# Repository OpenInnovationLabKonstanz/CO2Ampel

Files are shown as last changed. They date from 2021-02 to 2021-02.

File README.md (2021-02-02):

# CO2Ampel
A device for visual representation of  CO2 concentraition in the air. Helps monitoring air quality in order to reduce the risk of COVID19 infections in closed rooms.

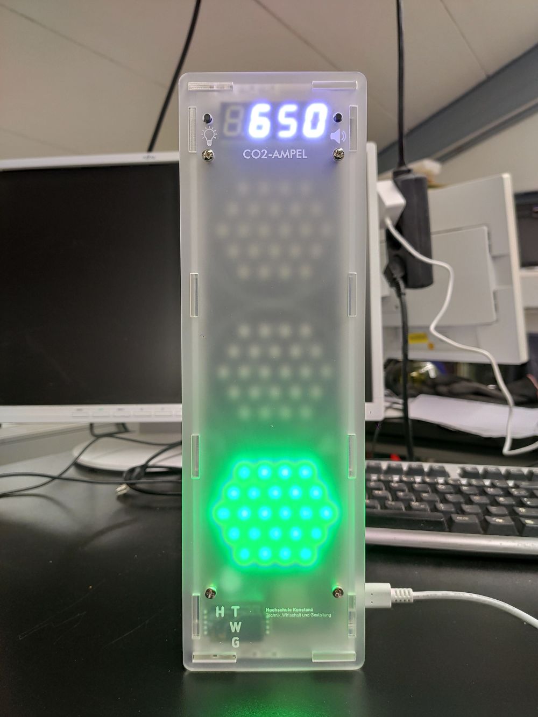
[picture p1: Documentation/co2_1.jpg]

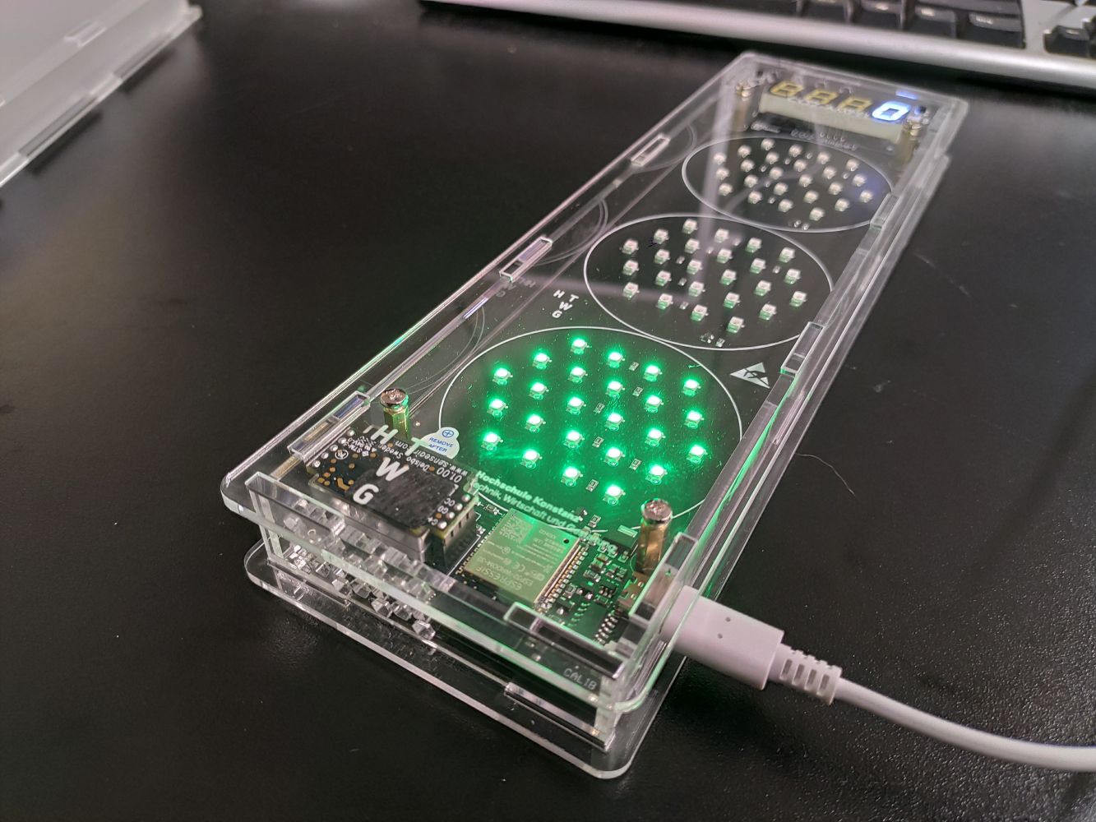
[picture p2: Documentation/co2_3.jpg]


## Project Overview

ToDo: ...

## Hardware

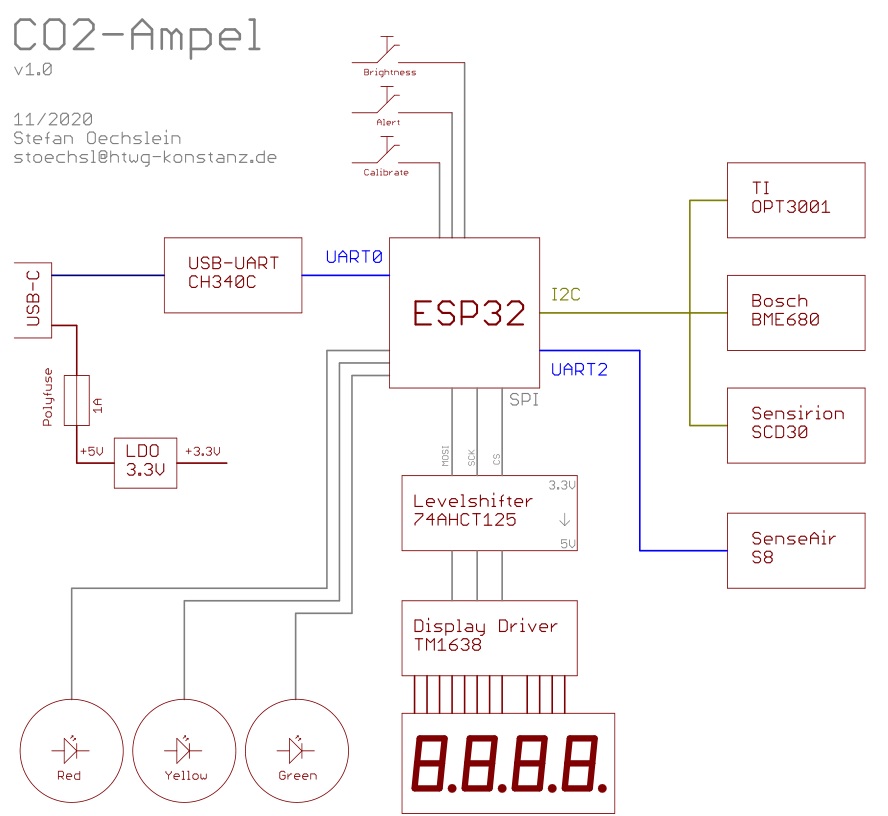
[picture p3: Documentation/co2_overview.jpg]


The device consists of a CO2 sensor, connected to a ESP32-WROOM-32 as main controller. Three large LED arrays (red, yellow, green) are used as a indicator for air quality. In addition, a numeric display shows the current CO2 concentration in ppm.

### CO2 Sensor
Due to the bad availability of CO2 sensors during the COVID19 pandemic, multiple sensor types are supported.
* SenseAir S8 (UART)
* MH-Z19B (pin-compatible to the S8)
* Sensirion SCD30 (I2C)

### Environment Sensor
As an additional method of air quality measurement, a Bosch BME680 multi environmental sensor is used. 
It provides temperature, rel. humidity, air pressure and VOC (volatile organic compounds) measurement.

### Ambient Light Sensor
In order to adapt the display and LED brightness, a OPT3001 ambient light 

### Display
A 4-digit 7-segment display, driven by a TitanMicro TM1638 is used to display the current CO2 concentration (in ppm).

## PCB
The PCB is routed as a 2-layer PCB. Parts are only placed on the top side in order to facilitate mass production.
Layout files are provided as Eagle 6.4 .brd and .sch files.

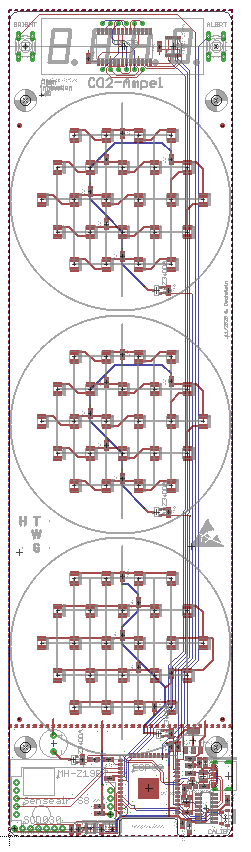
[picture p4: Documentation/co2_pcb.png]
PCB


## Software
The firmware for the ESP32 is written in Arduino, using the ESP32-Arduino support package.
It uses following external libraries:
* SparkFun SCD30 Library (ToDo: Link)
* ClosedCube OPT3001 Library (ToDo: Link)
* Adafruit Sensor Library (ToDo: Link)
* Adafruit BME680 Library (ToDo: Link)
* ...

## Mechanical
The housing is laser-cut from 3mm acrylic sheets. Use sheets with satin finish for better light dispersion (eg. TroGlass Satin).
DXF files for cutting and engraving are provided in *Mechanical*.

## Contact
Stefan Oechslein, Open Innovation Lab Konstanz, oil@htwg-konstanz.de

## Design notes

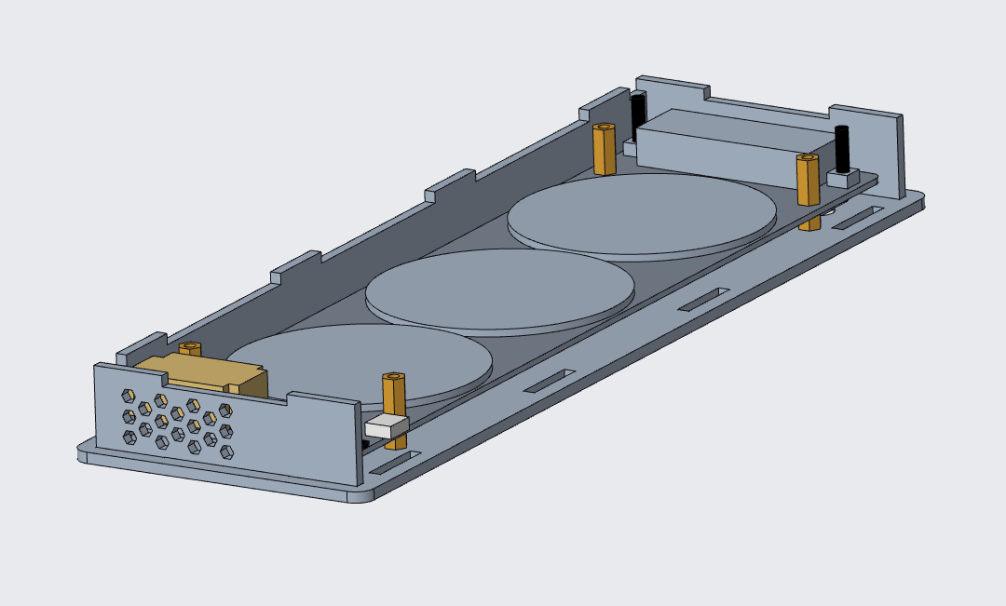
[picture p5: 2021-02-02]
Documentation/co2_cad1.png

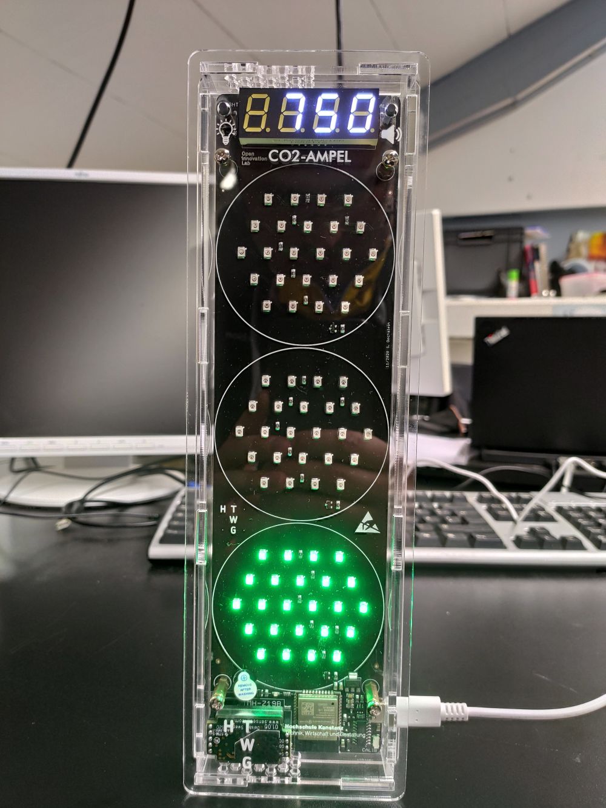
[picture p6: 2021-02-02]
Documentation/co2_2.jpg

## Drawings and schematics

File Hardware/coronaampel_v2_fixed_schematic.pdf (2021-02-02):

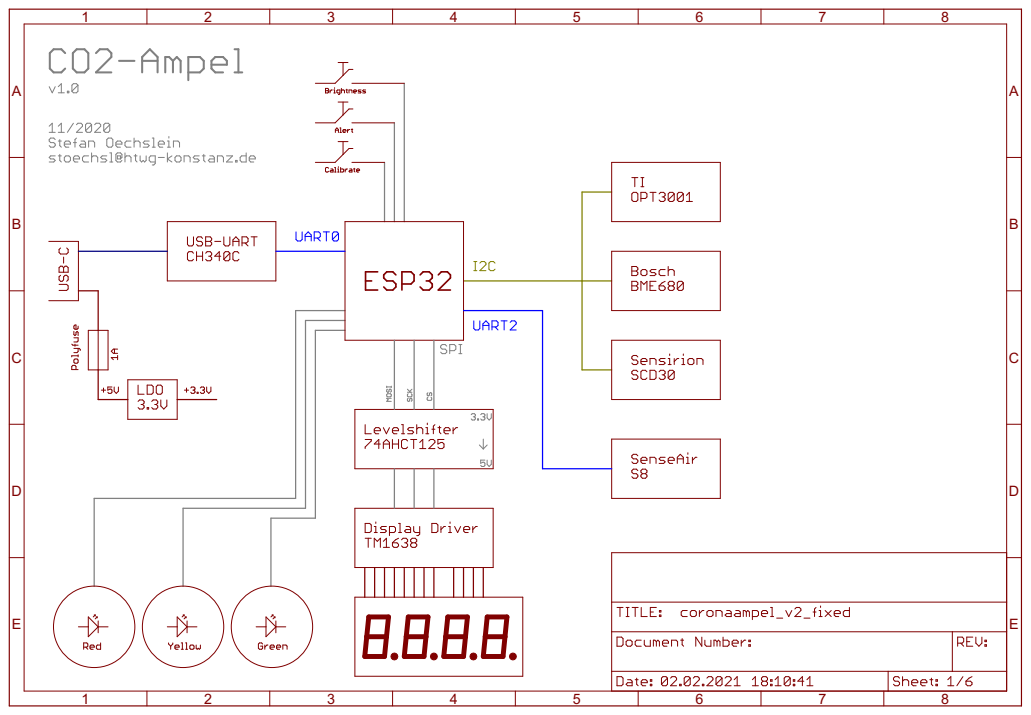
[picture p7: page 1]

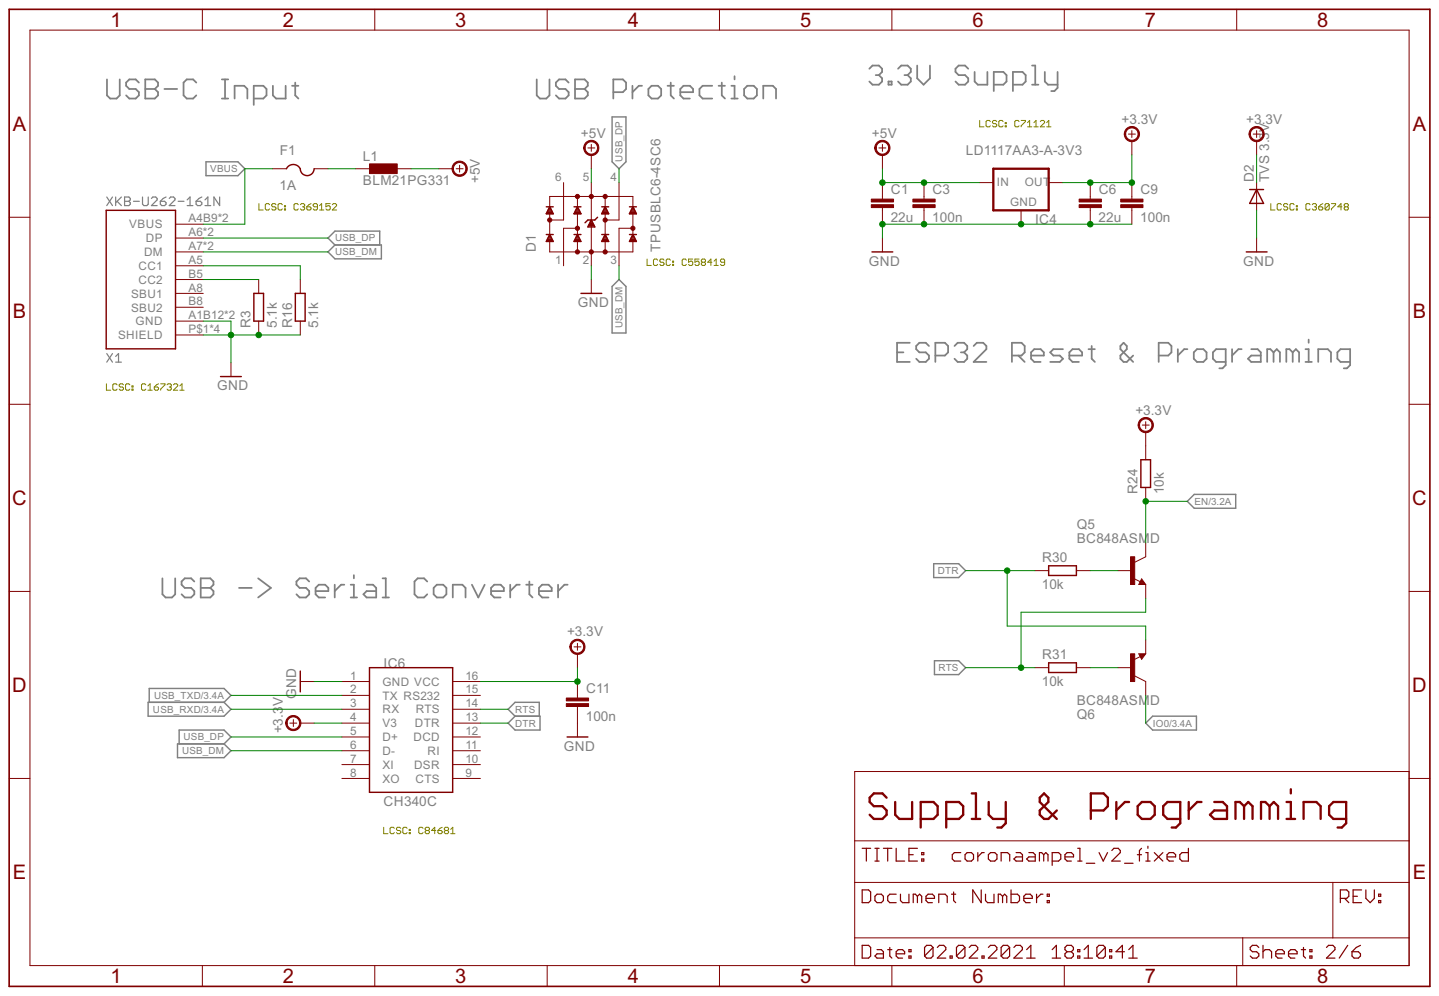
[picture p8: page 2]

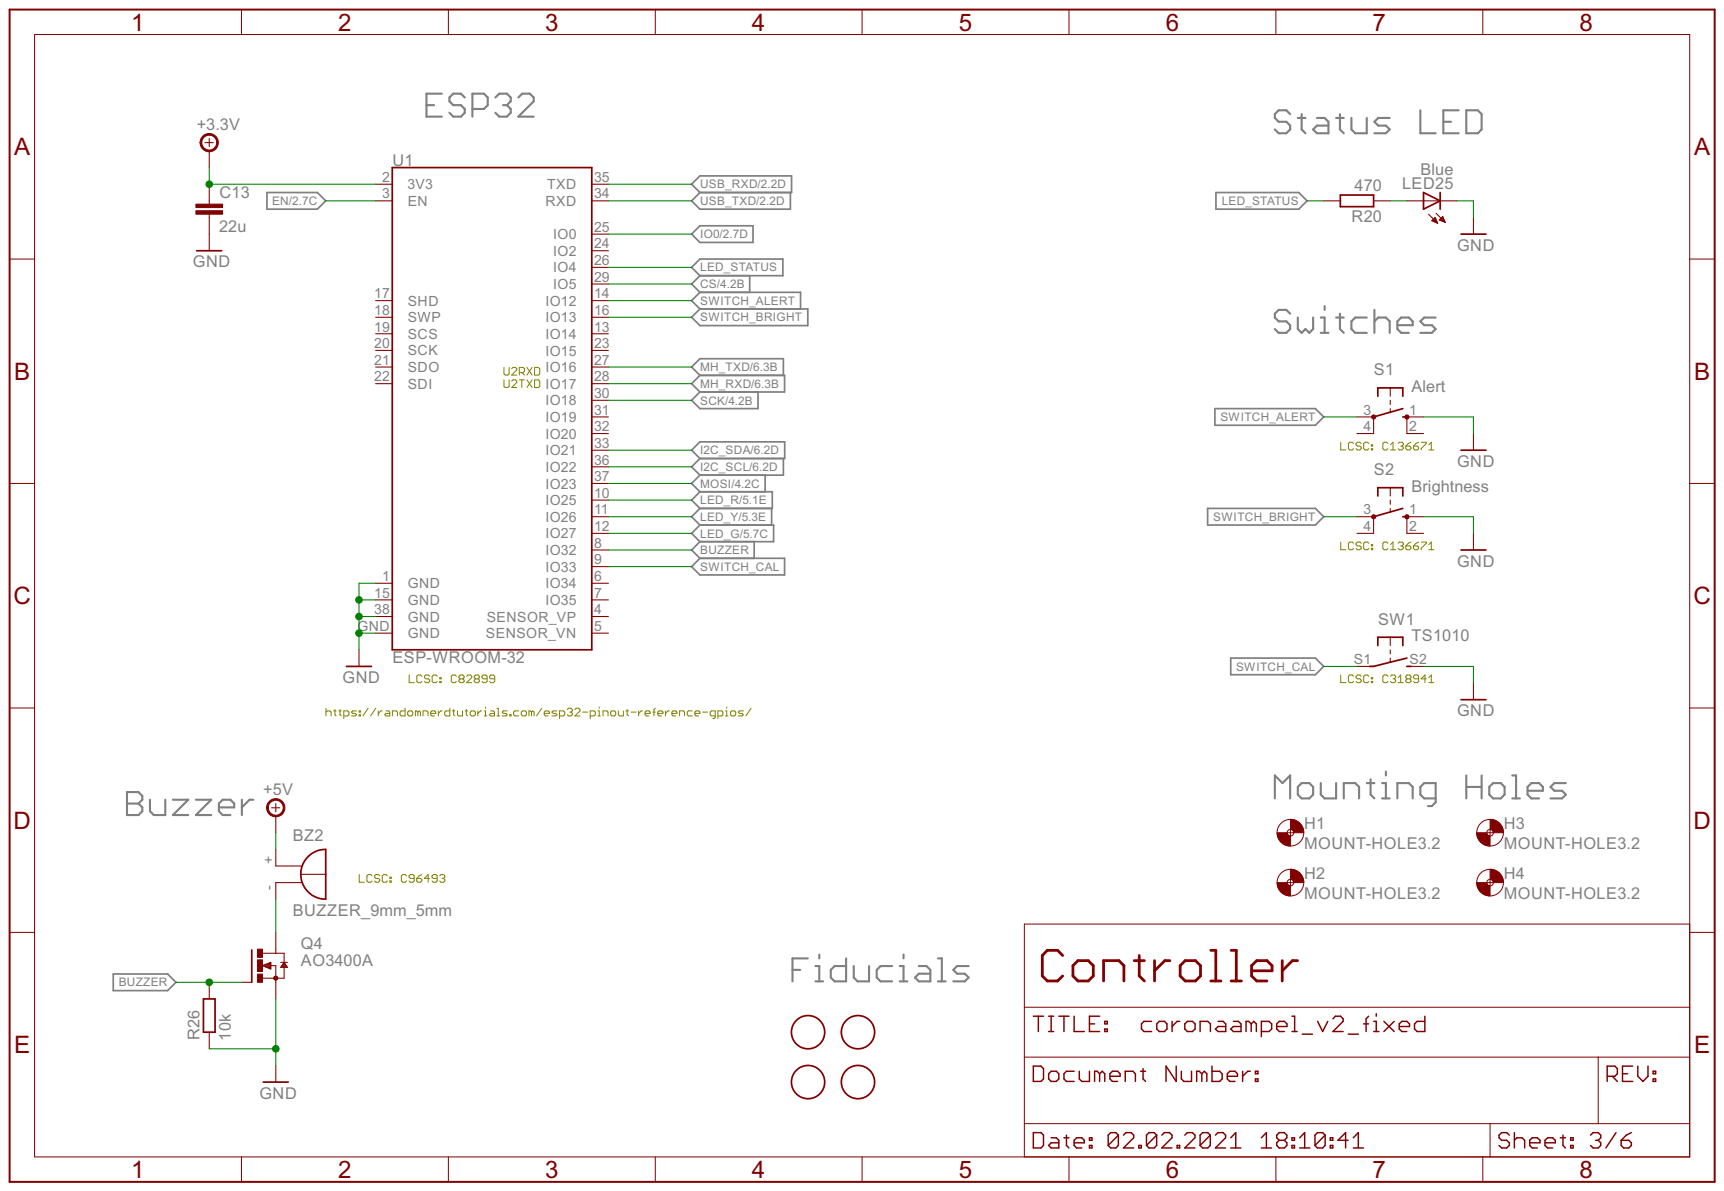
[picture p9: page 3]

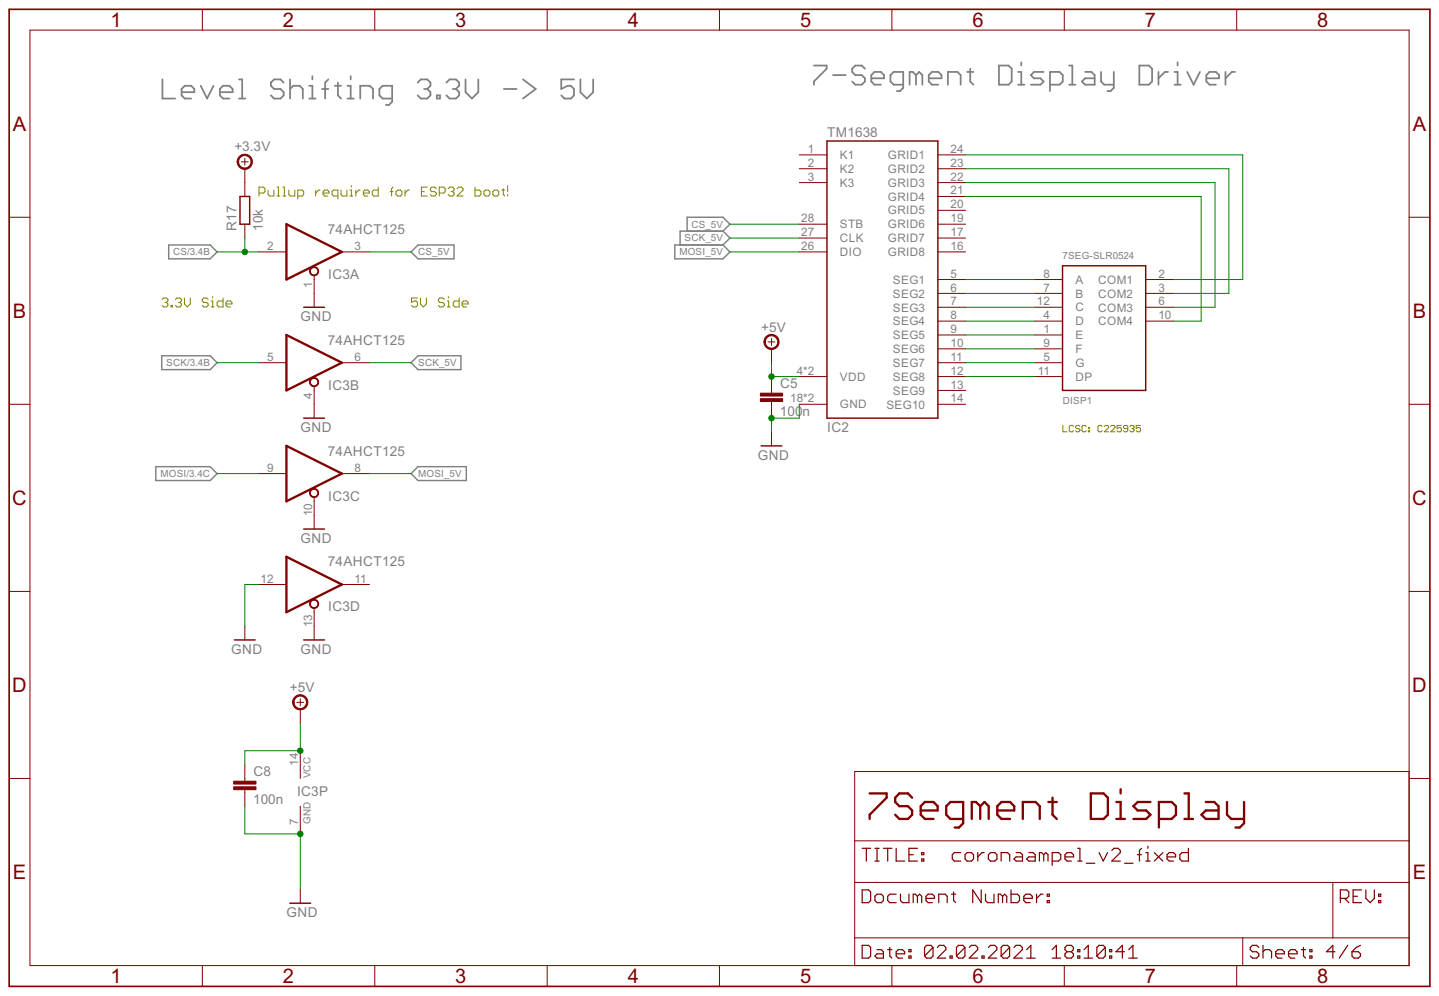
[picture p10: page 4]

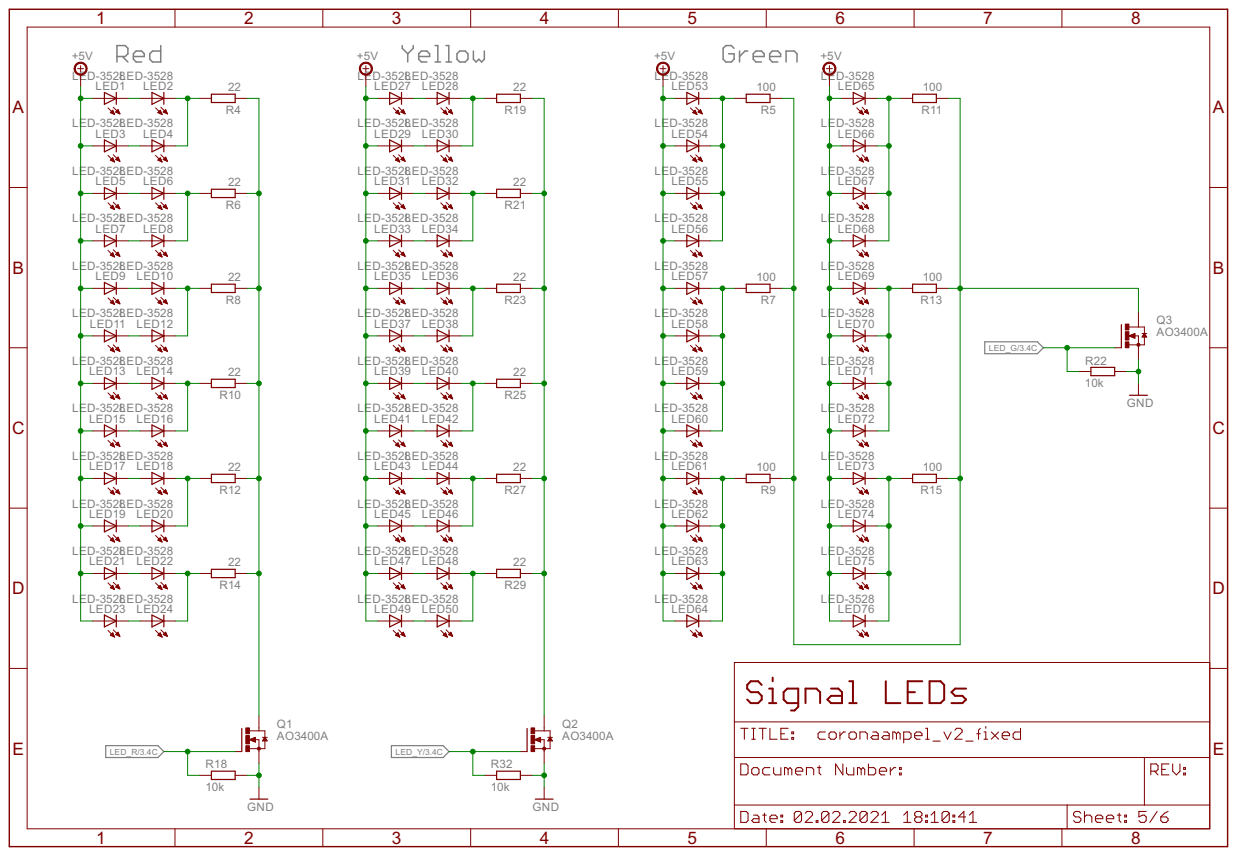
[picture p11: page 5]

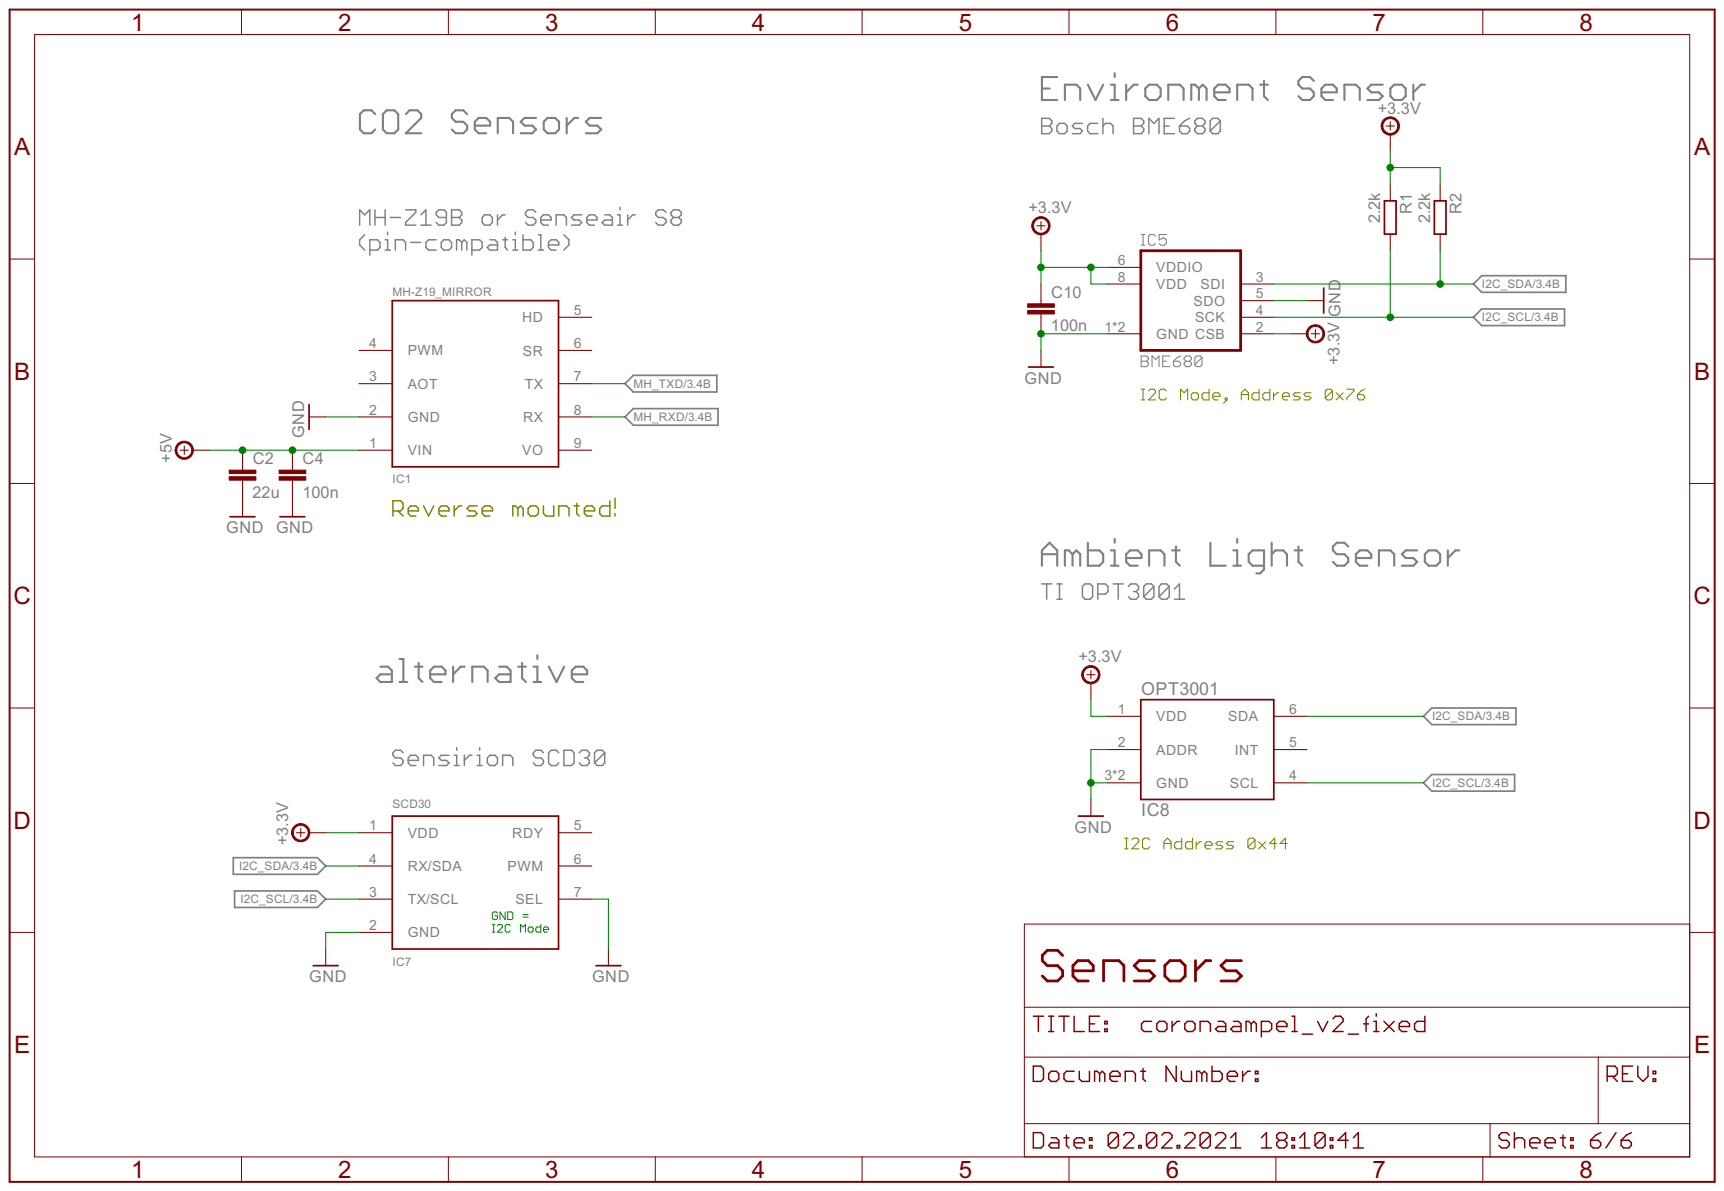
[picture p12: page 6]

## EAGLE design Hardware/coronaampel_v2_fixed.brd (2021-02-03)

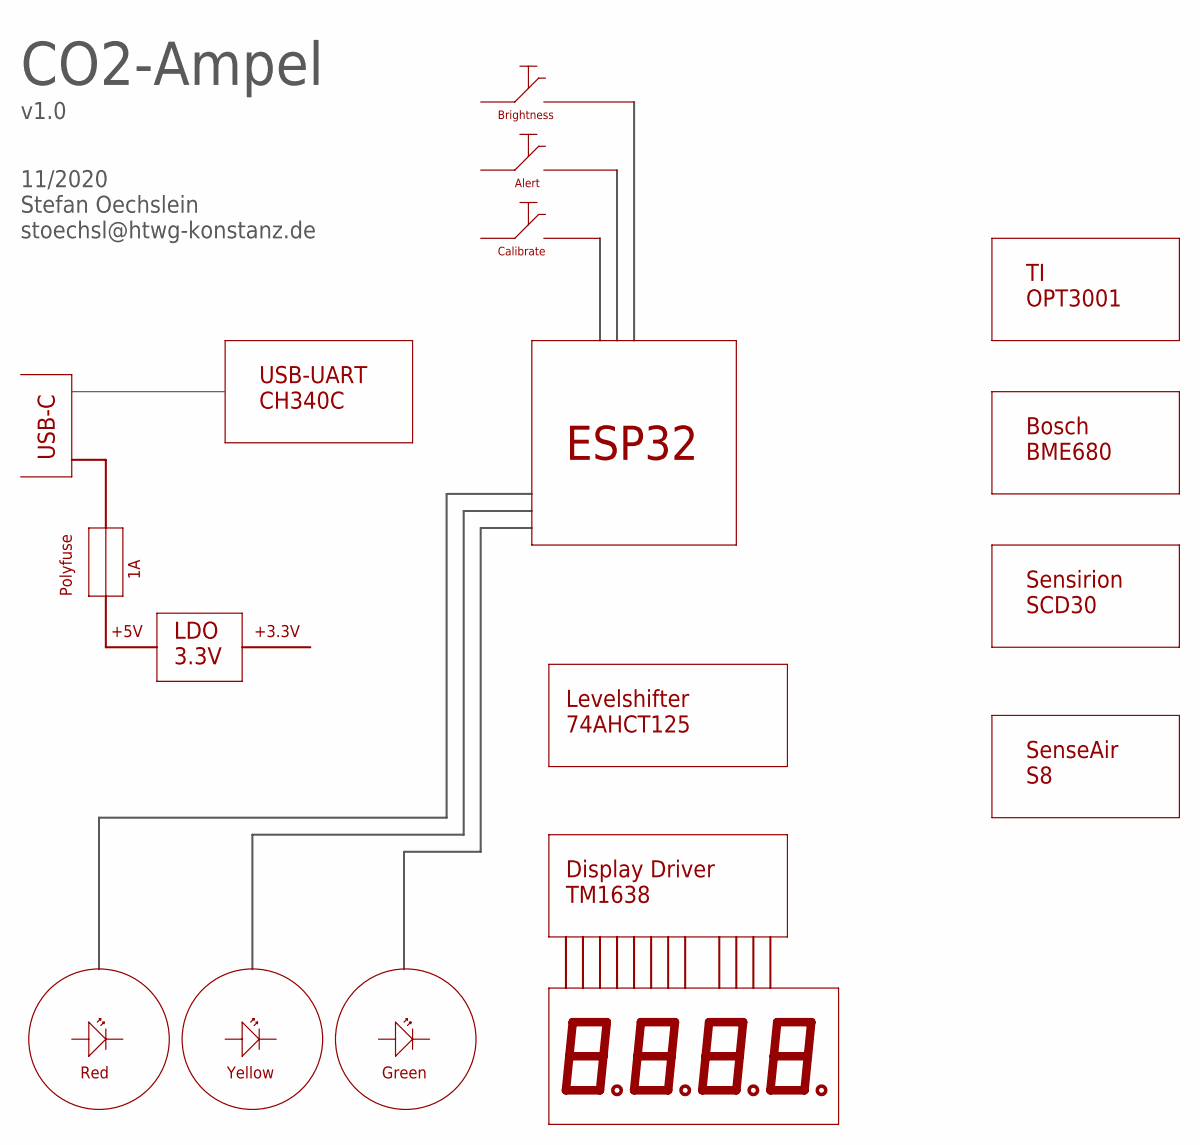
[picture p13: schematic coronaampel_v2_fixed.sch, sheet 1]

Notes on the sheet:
CO2-Ampel
ESP32
Sensirion SCD30
SenseAir S8
Bosch BME680
TI OPT3001
USB-UART CH340C
USB-C
LDO 3.3V
Display Driver TM1638
Levelshifter 74AHCT125
Polyfuse
+5V
+3.3V
Red
Yellow
Green
Alert
Calibrate
Brightness
v1.0
11/2020 Stefan Oechslein stoechsl@htwg-konstanz.de

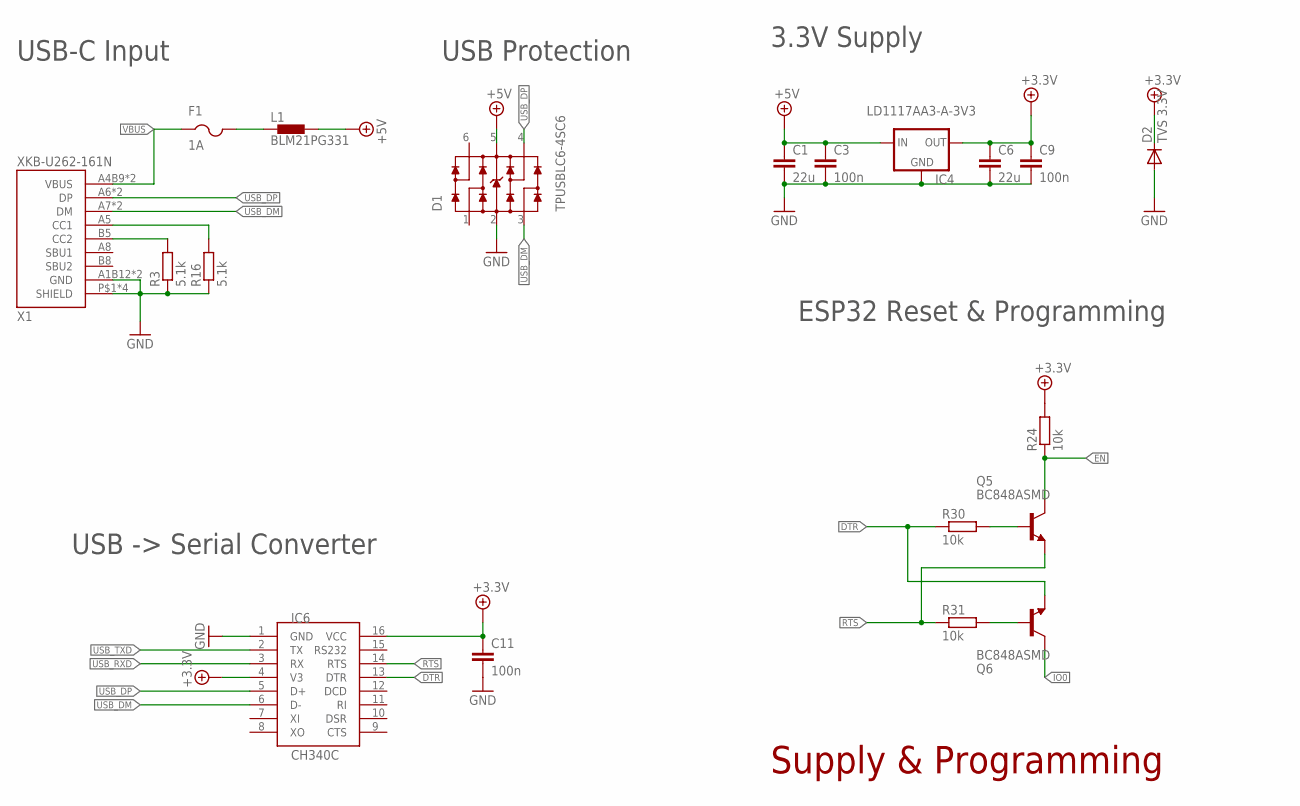
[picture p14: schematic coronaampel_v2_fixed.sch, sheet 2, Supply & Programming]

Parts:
C1, C6: 22u; C0805
C3, C9, C11: 100n; C0805
D1: TPUSBLC6-4SC6; WE-TVS_SOT23-6L
D2: TVS 3.3V; SOD123
F1: 1A; R0805
IC4: LD1117AA3-A-3V3; SOT223
IC6: CH340C; SOIC16
L1: BLM21PG331; 0805
Q5, Q6: BC848ASMD; SOT23
R3, R16: 5.1k; R0805
R24, R30, R31: 10k; R0805
X1: XKB-U262-161N; XKB_U262-161N

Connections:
+3,3V: C6.1, C9.1, C11.1, D2.C, IC4.2 (OUT), IC4.4 (OUT), IC6.4 (V3), IC6.16 (VCC), R24.2; also elsewhere on the board
+5V: C1.1, C3.1, D1.5 (VDD), IC4.3 (IN), L1.2; also elsewhere on the board
CC1: R16.2, X1.A5 (CC1)
CC2: R3.2, X1.B5 (CC2)
DTR: IC6.13 (DTR), Q6.2 (E), R30.1
EN: Q5.3 (C), R24.1; also elsewhere on the board
GND: C1.2, C3.2, C6.2, C9.2, C11.2, D1.2 (GND), D2.A, IC4.1 (GND), IC6.1 (GND), R3.1, R16.1, X1.A1B12 (GND), X1.B1A12 (GND), X1.P$1 (SHIELD), X1.P$2 (SHIELD), X1.P$3 (SHIELD), X1.P$4 (SHIELD); also elsewhere on the board
IO0: Q6.3 (C); also elsewhere on the board
unnamed: Q6.1 (B), R31.2
unnamed: Q5.1 (B), R30.2
RTS: IC6.14 (RTS), Q5.2 (E), R31.1
USB_DM: D1.3 (2), IC6.6 (D-), X1.A7 (DM), X1.B7 (DM)
USB_DP: D1.4 (3), IC6.5 (D+), X1.A6 (DP), X1.B6 (DP)
USB_RXD: IC6.3 (RX); also elsewhere on the board
USB_TXD: IC6.2 (TX); also elsewhere on the board
VBUS: F1.1, X1.A4B9 (VBUS), X1.B4A9 (VBUS)
VIN: F1.2, L1.1

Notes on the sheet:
USB -> Serial Converter
ESP32 Reset & Programming
USB-C Input
USB Protection
3.3V Supply
Supply & Programming

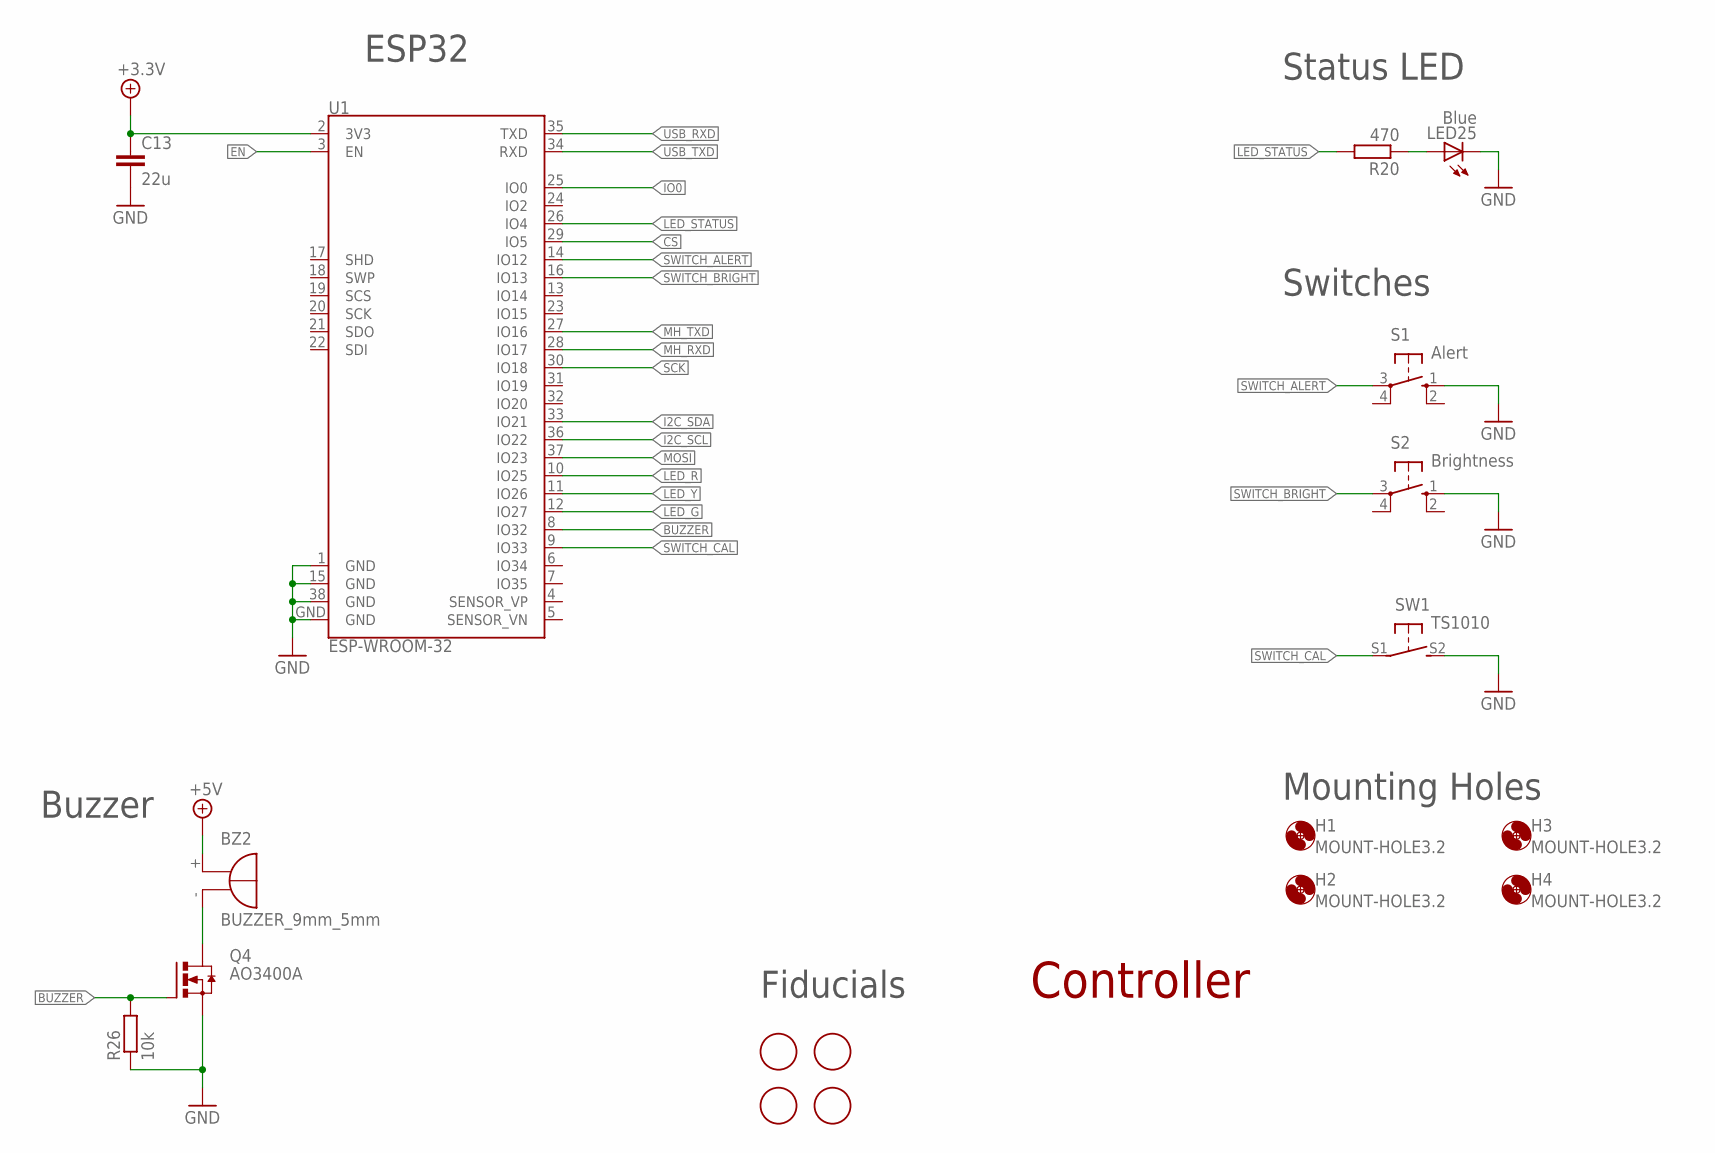
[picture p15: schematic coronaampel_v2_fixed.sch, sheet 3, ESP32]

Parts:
BZ2: BUZZER_9mm_5mm; BUZ_9_5
C13: 22u; C0805
H1, H2, H3, H4: MOUNT-HOLE3.2; 3,2
LED25: Blue; CHIPLED_0805
Q4: AO3400A; MICRO3
R20: 470; R0805
R26: 10k; R0805
S1: Alert; B3F-10XX
S2: Brightness; B3F-10XX
SW1: TS1010
U1: ESP-WROOM-32
U$4, U$6, U$7, U$8: FIDUCIAL; FIDUCIAL_1MM

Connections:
+3,3V: C13.1, U1.2 (3V3); also elsewhere on the board
+5V: BZ2.+; also elsewhere on the board
BUZ: BZ2.-, Q4.3 (D)
BUZZER: Q4.1 (G), R26.2, U1.8 (IO32)
CS: U1.29 (IO5); also elsewhere on the board
EN: U1.3 (EN); also elsewhere on the board
GND: C13.2, LED25.C, Q4.2 (S), R26.1, S1.1 (S), S2.1 (S), SW1.S2 (S), U1.1 (GND), U1.15 (GND), U1.38 (GND), U1.GND; also elsewhere on the board
I2C_SCL: U1.36 (IO22); also elsewhere on the board
I2C_SDA: U1.33 (IO21); also elsewhere on the board
IO0: U1.25 (IO0); also elsewhere on the board
LED_G: U1.12 (IO27); also elsewhere on the board
LED_R: U1.10 (IO25); also elsewhere on the board
LED_STATUS: R20.2, U1.26 (IO4)
LED_Y: U1.11 (IO26); also elsewhere on the board
MH_RXD: U1.28 (IO17); also elsewhere on the board
MH_TXD: U1.27 (IO16); also elsewhere on the board
MOSI: U1.37 (IO23); also elsewhere on the board
unnamed: LED25.A, R20.1
SCK: U1.30 (IO18); also elsewhere on the board
SWITCH_ALERT: S1.3, U1.14 (IO12)
SWITCH_BRIGHT: S2.3, U1.16 (IO13)
SWITCH_CAL: SW1.S1, U1.9 (IO33)
USB_RXD: U1.35 (TXD); also elsewhere on the board
USB_TXD: U1.34 (RXD); also elsewhere on the board

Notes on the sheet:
Buzzer
Status LED
Switches
ESP32
Controller
Fiducials
Mounting Holes

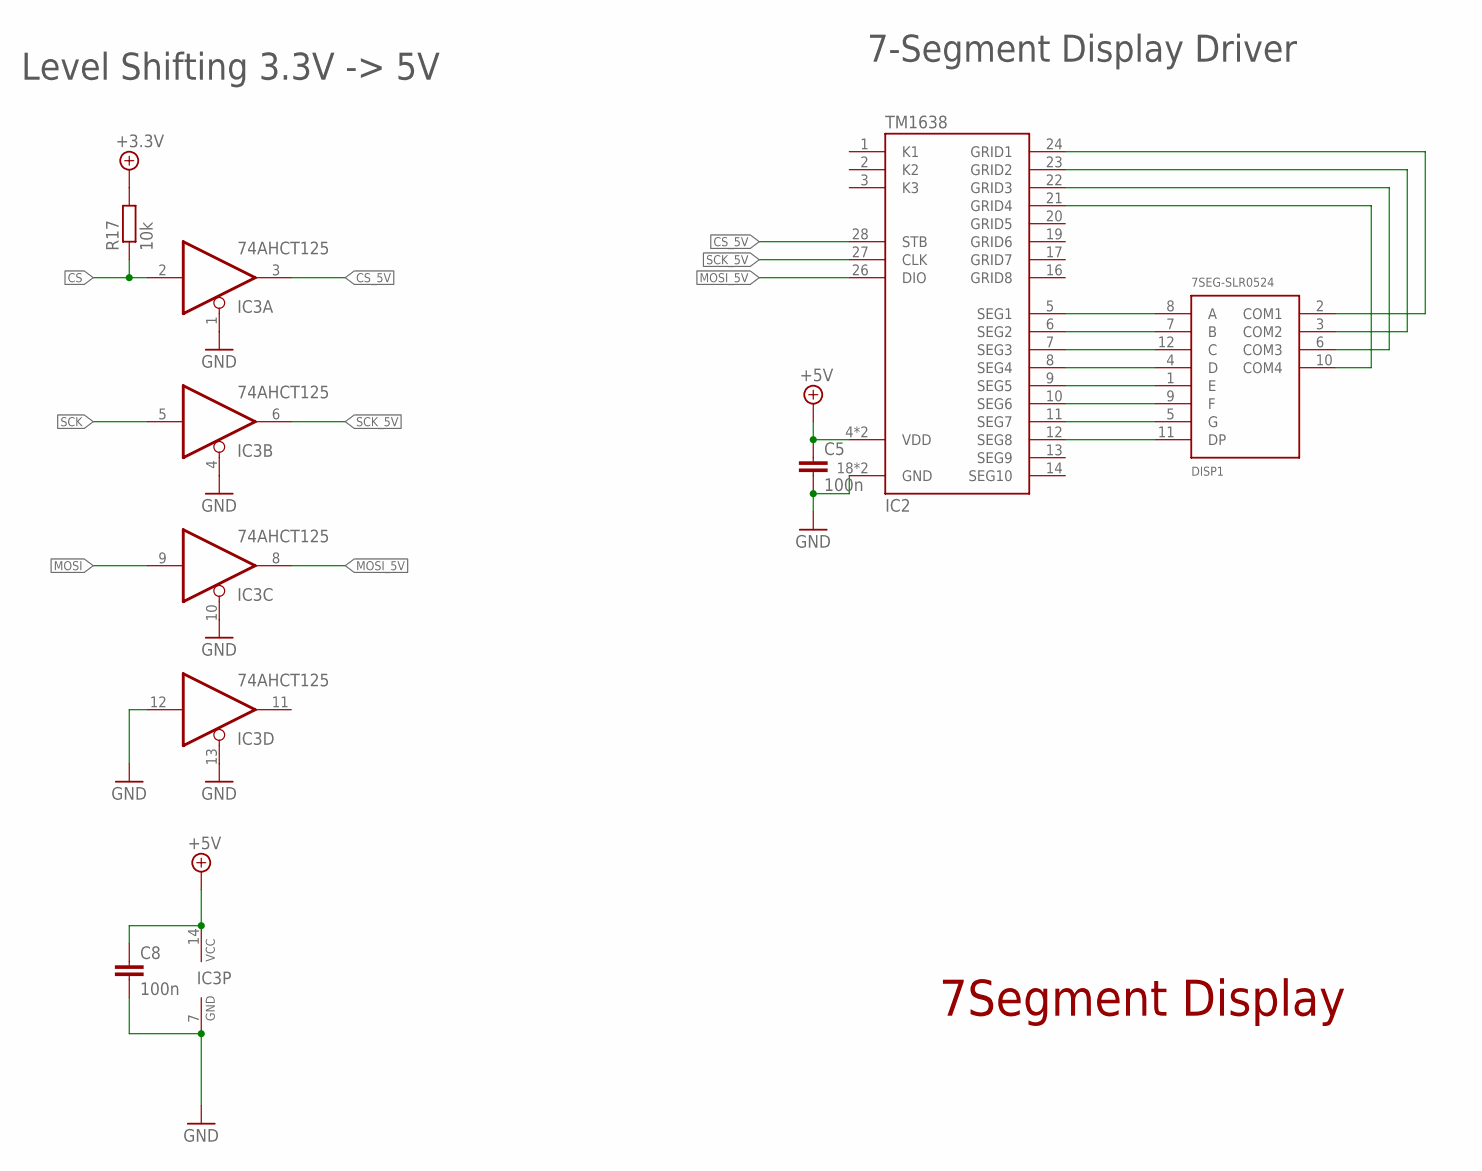
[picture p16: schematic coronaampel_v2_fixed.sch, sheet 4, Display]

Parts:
C5, C8: 100n; C0805
DISP1: 7SEG-SLR0524; SEG-SLR0524
IC2: TM1638; SO-28L
IC3: 74AHCT125; TSSOP14
R17: 10k; R0805

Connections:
+3,3V: R17.2; also elsewhere on the board
+5V: C5.1, C8.1, IC2.4 (VDD), IC2.15 (VDD), IC3.14 (VCC); also elsewhere on the board
CS: IC3.2 (I), R17.1; also elsewhere on the board
CS_5V: IC2.28 (STB), IC3.3 (O)
GND: C5.2, C8.2, IC2.18 (GND), IC2.25 (GND), IC3.1 (OE), IC3.4 (OE), IC3.7 (GND), IC3.10 (OE), IC3.12 (I), IC3.13 (OE); also elsewhere on the board
GRID1: DISP1.2 (COM1), IC2.24 (GRID1)
GRID2: DISP1.3 (COM2), IC2.23 (GRID2)
GRID3: DISP1.6 (COM3), IC2.22 (GRID3)
GRID4: DISP1.10 (COM4), IC2.21 (GRID4)
MOSI: IC3.9 (I); also elsewhere on the board
MOSI_5V: IC2.26 (DIO), IC3.8 (O)
SCK: IC3.5 (I); also elsewhere on the board
SCK_5V: IC2.27 (CLK), IC3.6 (O)
SEG1: DISP1.8 (A), IC2.5 (SEG1)
SEG2: DISP1.7 (B), IC2.6 (SEG2)
SEG3: DISP1.12 (C), IC2.7 (SEG3)
SEG4: DISP1.4 (D), IC2.8 (SEG4)
SEG5: DISP1.1 (E), IC2.9 (SEG5)
SEG6: DISP1.9 (F), IC2.10 (SEG6)
SEG7: DISP1.5 (G), IC2.11 (SEG7)
SEG8: DISP1.11 (DP), IC2.12 (SEG8)

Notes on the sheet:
Level Shifting 3.3V -> 5V
7-Segment Display Driver
7Segment Display

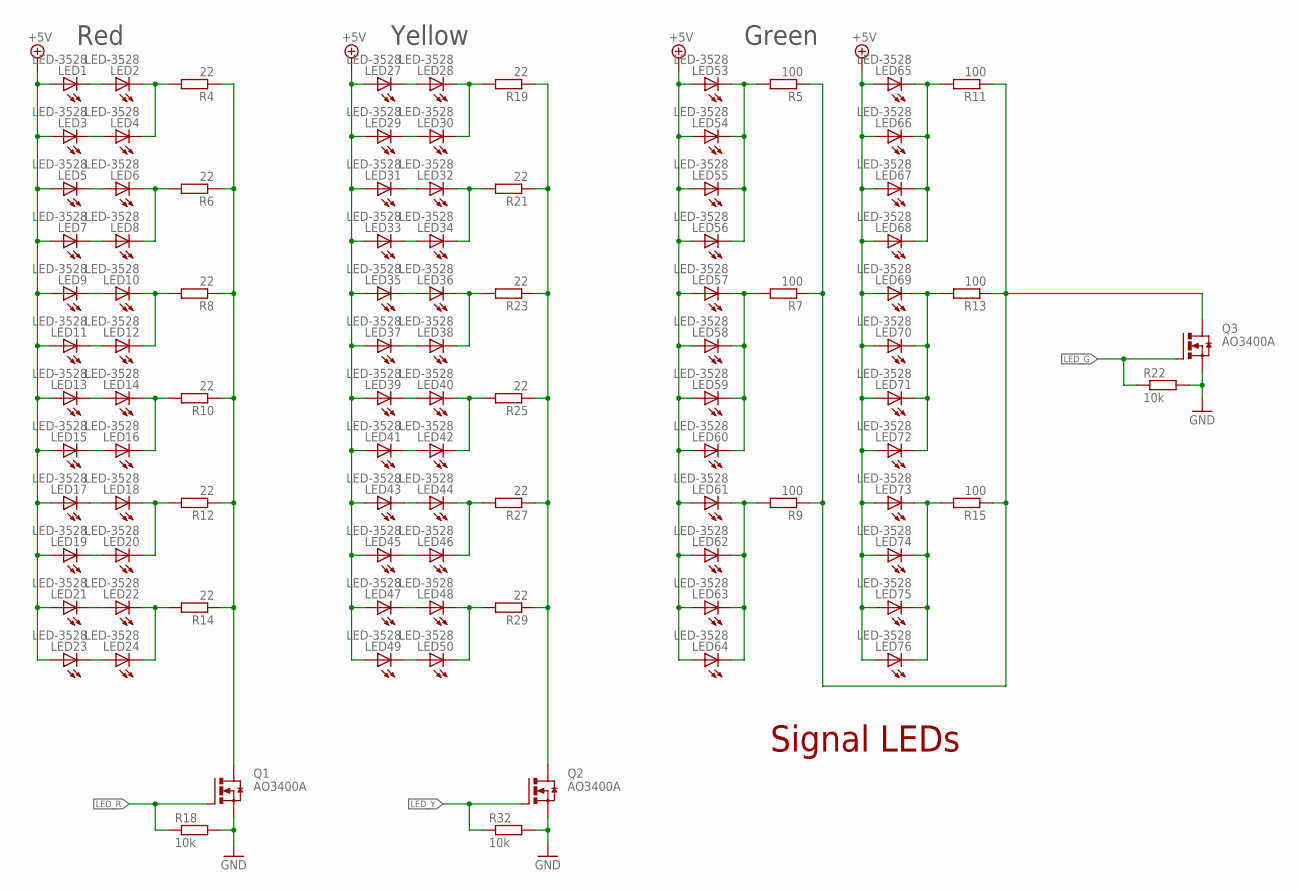
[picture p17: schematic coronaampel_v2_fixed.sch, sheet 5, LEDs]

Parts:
LED1, LED2, LED3, LED4, LED5, LED6, LED7, LED8, LED9, LED10, LED11, LED12, LED13, LED14, LED15, LED16, LED17, LED18, LED19, LED20, LED21, LED22, LED23, LED24, LED27, LED28, LED29, LED30, LED31, LED32, LED33, LED34, LED35, LED36, LED37, LED38, LED39, LED40, LED41, LED42, LED43, LED44, LED45, LED46, LED47, LED48, LED49, LED50, LED53, LED54, LED55, LED56, LED57, LED58, LED59, LED60, LED61, LED62, LED63, LED64, LED65, LED66, LED67, LED68, LED69, LED70, LED71, LED72, LED73, LED74, LED75, LED76: LED-3528; 3528
Q1, Q2, Q3: AO3400A; MICRO3
R4, R6, R8, R10, R12, R14, R19, R21, R23, R25, R27, R29: 22; R0805
R5, R7, R9, R11, R13, R15: 100; R0805
R18, R22, R32: 10k; R0805

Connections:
+5V: LED1.A, LED3.A, LED5.A, LED7.A, LED9.A, LED11.A, LED13.A, LED15.A, LED17.A, LED19.A, LED21.A, LED23.A, LED27.A, LED29.A, LED31.A, LED33.A, LED35.A, LED37.A, LED39.A, LED41.A, LED43.A, LED45.A, LED47.A, LED49.A, LED53.A, LED54.A, LED55.A, LED56.A, LED57.A, LED58.A, LED59.A, LED60.A, LED61.A, LED62.A, LED63.A, LED64.A, LED65.A, LED66.A, LED67.A, LED68.A, LED69.A, LED70.A, LED71.A, LED72.A, LED73.A, LED74.A, LED75.A, LED76.A; also elsewhere on the board
GND: Q1.2 (S), Q2.2 (S), Q3.2 (S), R18.2, R22.2, R32.2; also elsewhere on the board
LED_G: Q3.1 (G), R22.1; also elsewhere on the board
LED_G_GND: Q3.3 (D), R5.1, R7.1, R9.1, R11.1, R13.1, R15.1
LED_R: Q1.1 (G), R18.1; also elsewhere on the board
LED_R_GND: Q1.3 (D), R4.1, R6.1, R8.1, R10.1, R12.1, R14.1
LED_Y: Q2.1 (G), R32.1; also elsewhere on the board
LED_Y_GND: Q2.3 (D), R19.1, R21.1, R23.1, R25.1, R27.1, R29.1
unnamed: LED1.C, LED2.A
unnamed: LED3.C, LED4.A
unnamed: LED5.C, LED6.A
unnamed: LED2.C, LED4.C, R4.2
unnamed: LED53.C, LED54.C, LED55.C, LED56.C, R5.2
unnamed: LED6.C, LED8.C, R6.2
unnamed: LED7.C, LED8.A
unnamed: LED9.C, LED10.A
unnamed: LED11.C, LED12.A
unnamed: LED10.C, LED12.C, R8.2
unnamed: LED57.C, LED58.C, LED59.C, LED60.C, R7.2
unnamed: LED13.C, LED14.A
unnamed: LED15.C, LED16.A
unnamed: LED17.C, LED18.A
unnamed: LED14.C, LED16.C, R10.2
unnamed: LED18.C, LED20.C, R12.2
unnamed: LED19.C, LED20.A
unnamed: LED61.C, LED62.C, LED63.C, LED64.C, R9.2
unnamed: LED21.C, LED22.A
unnamed: LED23.C, LED24.A
unnamed: LED22.C, LED24.C, R14.2
unnamed: LED27.C, LED28.A
unnamed: LED29.C, LED30.A
unnamed: LED31.C, LED32.A
unnamed: LED28.C, LED30.C, R19.2
unnamed: LED65.C, LED66.C, LED67.C, LED68.C, R11.2
unnamed: LED32.C, LED34.C, R21.2
unnamed: LED33.C, LED34.A
unnamed: LED35.C, LED36.A
unnamed: LED37.C, LED38.A
unnamed: LED36.C, LED38.C, R23.2
unnamed: LED69.C, LED70.C, LED71.C, LED72.C, R13.2
unnamed: LED39.C, LED40.A
unnamed: LED41.C, LED42.A
unnamed: LED43.C, LED44.A
unnamed: LED40.C, LED42.C, R25.2
unnamed: LED73.C, LED74.C, LED75.C, LED76.C, R15.2
unnamed: LED44.C, LED46.C, R27.2
unnamed: LED45.C, LED46.A
unnamed: LED47.C, LED48.A
unnamed: LED49.C, LED50.A
unnamed: LED48.C, LED50.C, R29.2

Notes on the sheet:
Red
Yellow
Green
Signal LEDs

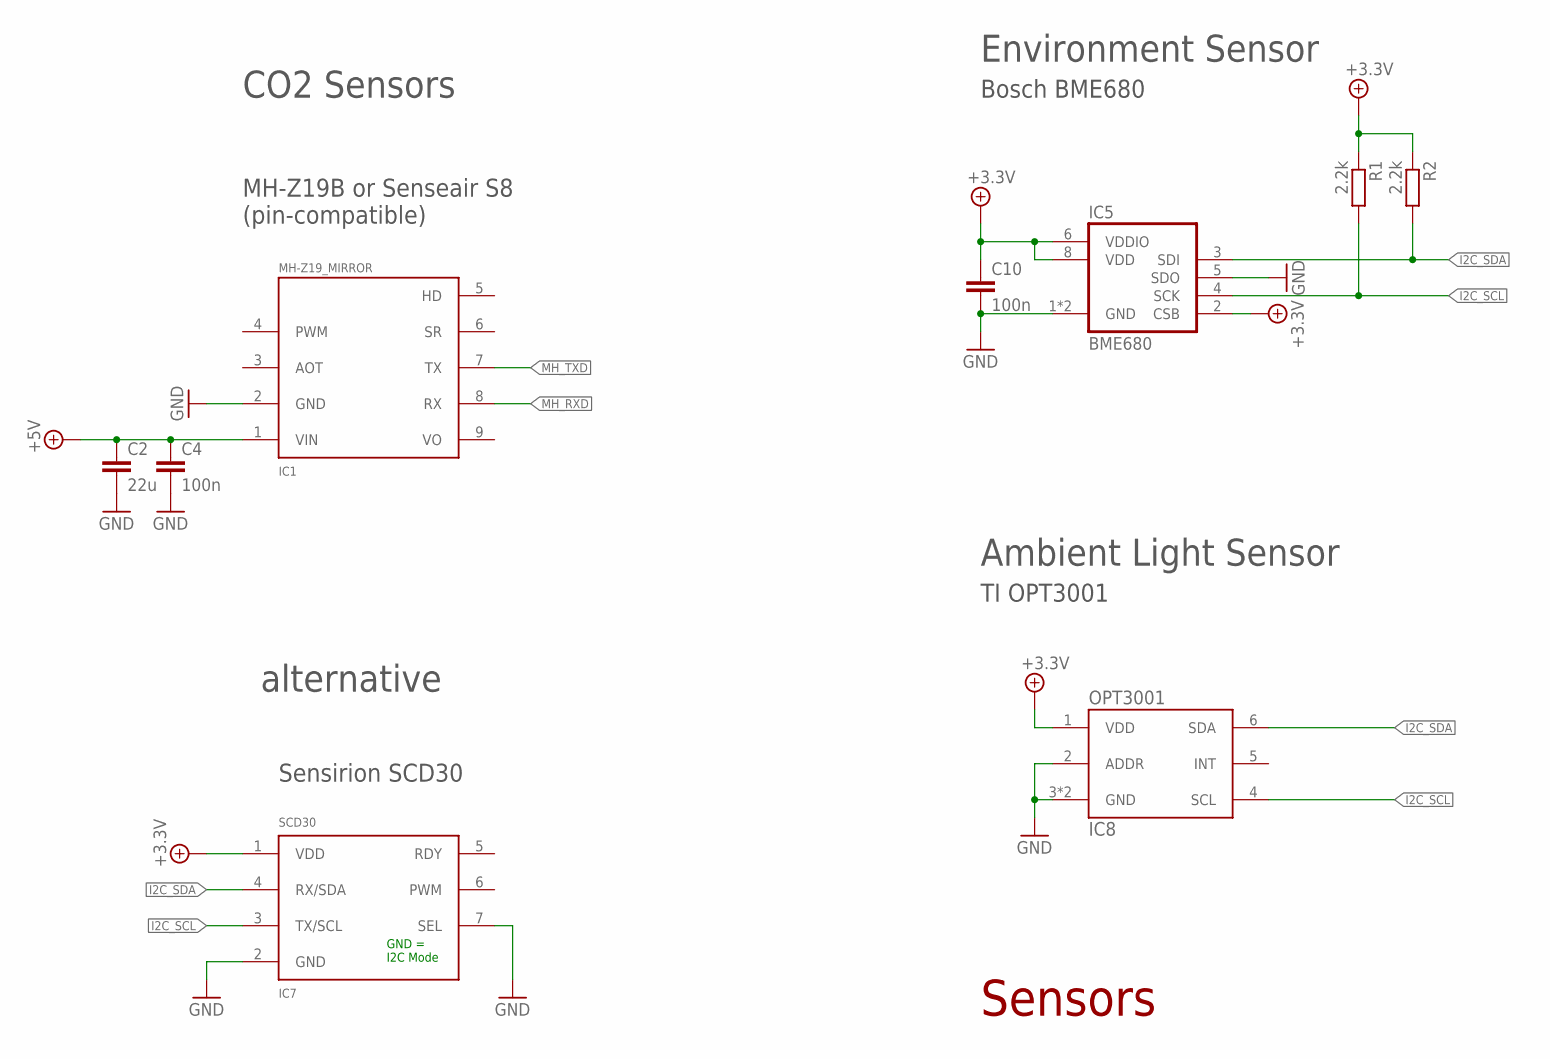
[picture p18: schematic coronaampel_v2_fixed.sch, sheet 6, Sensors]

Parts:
C2: 22u; C0805
C4, C10: 100n; C0805
IC1: MH-Z19_MIRROR
IC5: BME680
IC7: SCD30
IC8: OPT3001; USON6
R1, R2: 2.2k; R0805

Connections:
+3,3V: C10.1, IC5.2 (CSB), IC5.6 (VDDIO), IC5.8 (VDD), IC7.1 (VDD), IC8.1 (VDD), R1.1, R2.1; also elsewhere on the board
+5V: C2.1, C4.1, IC1.1 (VIN); also elsewhere on the board
GND: C2.2, C4.2, C10.2, IC1.2 (GND), IC5.1 (GND), IC5.5 (SDO), IC5.7 (GND), IC7.2 (GND), IC7.7 (SEL), IC8.2 (ADDR), IC8.3 (GND), IC8.EP (GND); also elsewhere on the board
I2C_SCL: IC5.4 (SCK), IC7.3 (TX/SCL), IC8.4 (SCL), R1.2; also elsewhere on the board
I2C_SDA: IC5.3 (SDI), IC7.4 (RX/SDA), IC8.6 (SDA), R2.2; also elsewhere on the board
MH_RXD: IC1.8 (RX); also elsewhere on the board
MH_TXD: IC1.7 (TX); also elsewhere on the board

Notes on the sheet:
GND = I2C Mode
CO2 Sensors
MH-Z19B or Senseair S8 (pin-compatible)
Sensirion SCD30
Bosch BME680
TI OPT3001
Ambient Light Sensor
Environment Sensor
Sensors
alternative

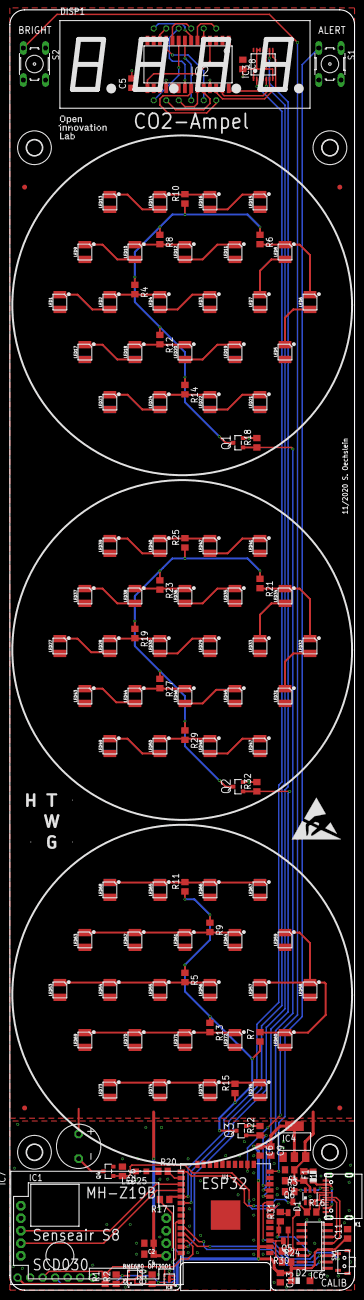
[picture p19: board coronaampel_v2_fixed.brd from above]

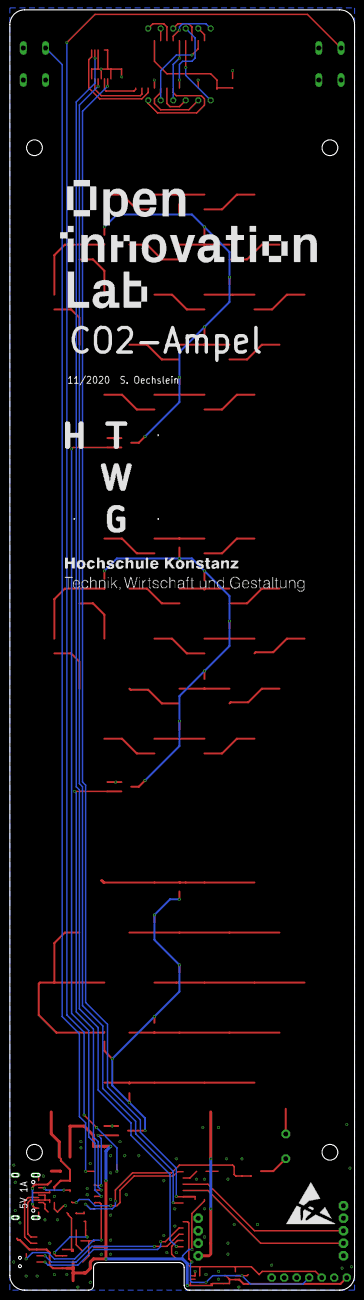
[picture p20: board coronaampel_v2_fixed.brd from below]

Board: 2 copper layers, 70.0 x 260.0 mm, 155 parts (4 on the bottom side), 94 nets.

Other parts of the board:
U$1, U$5: ESD_10.00
U$2: OIL_LOGO_10
U$3: OIL_LOGO_50
U$9: HTWG_10
U$10: HTWG_TEXT_8
U$11: HTWG_20

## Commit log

2021-02-02 Added PCB files and schematic
    [coronaampel_v2_fixed.brd, coronaampel_v2_fixed.sch]
2021-02-03 fixed board file, added gerbers
    [coronaampel_v2_fixed.brd]

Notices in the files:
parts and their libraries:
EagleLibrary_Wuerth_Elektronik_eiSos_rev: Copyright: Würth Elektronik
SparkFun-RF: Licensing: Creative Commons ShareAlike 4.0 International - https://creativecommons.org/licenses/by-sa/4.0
